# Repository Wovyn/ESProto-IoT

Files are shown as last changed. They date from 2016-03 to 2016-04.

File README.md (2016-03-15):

# ESProto-IoT

The ESProto IoT is an ESP8266 prototyping PCB made for the AI Thinker ESP-12F modules, and designed to support IoT ("Internet of Things") sensors and peripherals from SeeedStudio/Grove, DFRobot, and ControlEverything.

## How does it work?

The ESP8266 is more powerful than the Arduino Pro Mini--so why not use it as the "main" microcontroller, and drive the Arduino Pro Mini as a peripheral? We do that by communicating with the Arduino Pro Mini over I2C ("I-squared-C"). The advantage to this arrangement is a board that can speak to all of the 5V sensors and actuators that already work with your Arduino, with the added speed and WiFi capability of the ESP8266.

## Design Images

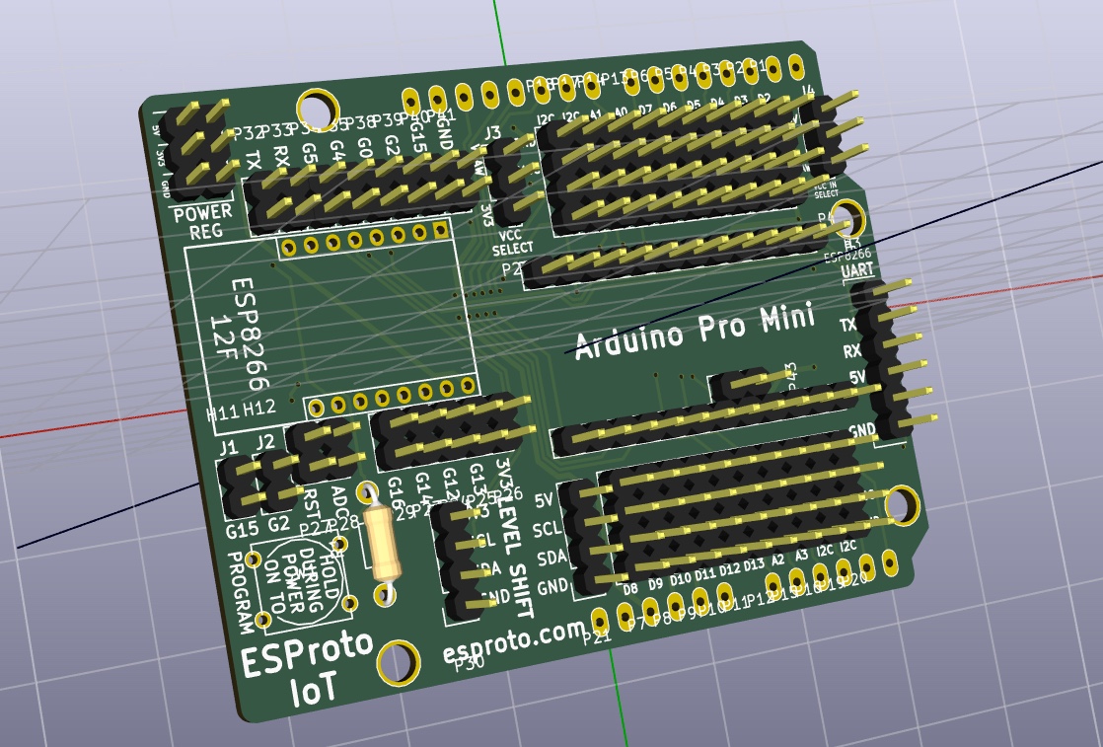
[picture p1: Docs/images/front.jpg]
Front


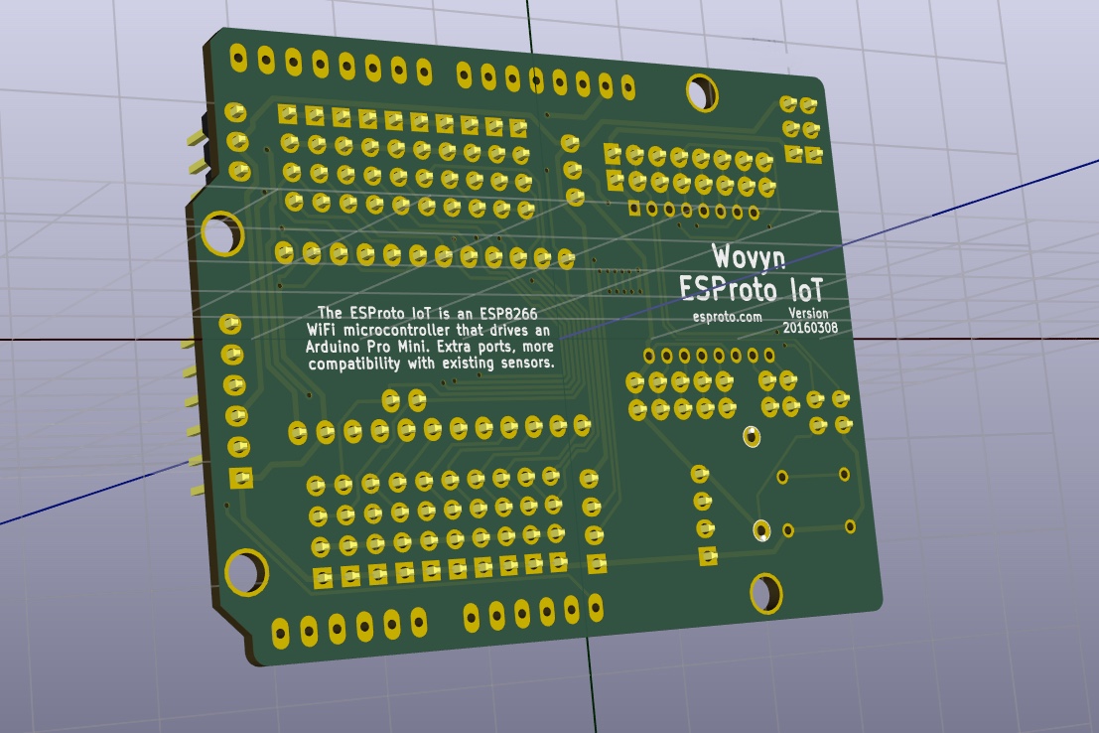
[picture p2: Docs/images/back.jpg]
Back


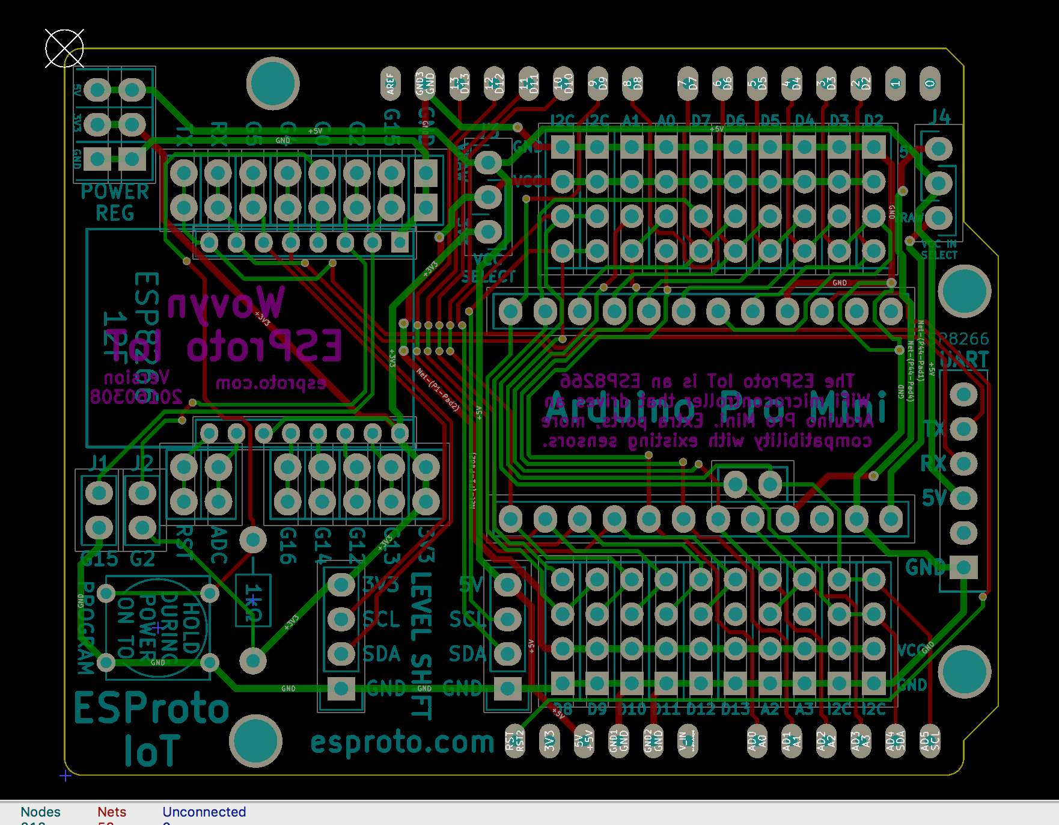
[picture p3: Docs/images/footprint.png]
Footprint


## PDFs

[View PDFs](Docs/PDF)

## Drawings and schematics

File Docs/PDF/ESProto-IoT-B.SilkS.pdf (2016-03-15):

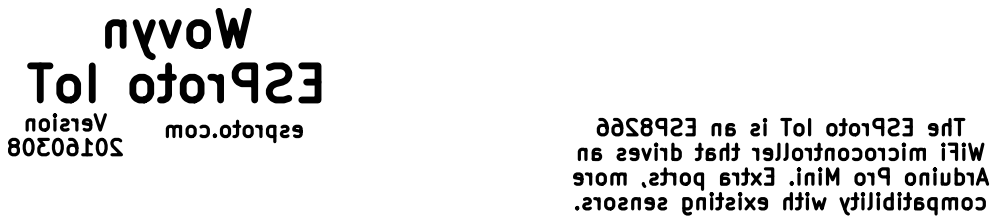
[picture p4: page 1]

20160308 The ESProto IoT is an ESP8266 WiFi microcontroller that drives an Arduino Pro Mini. Extra ports, more

compatibility with existing sensors.

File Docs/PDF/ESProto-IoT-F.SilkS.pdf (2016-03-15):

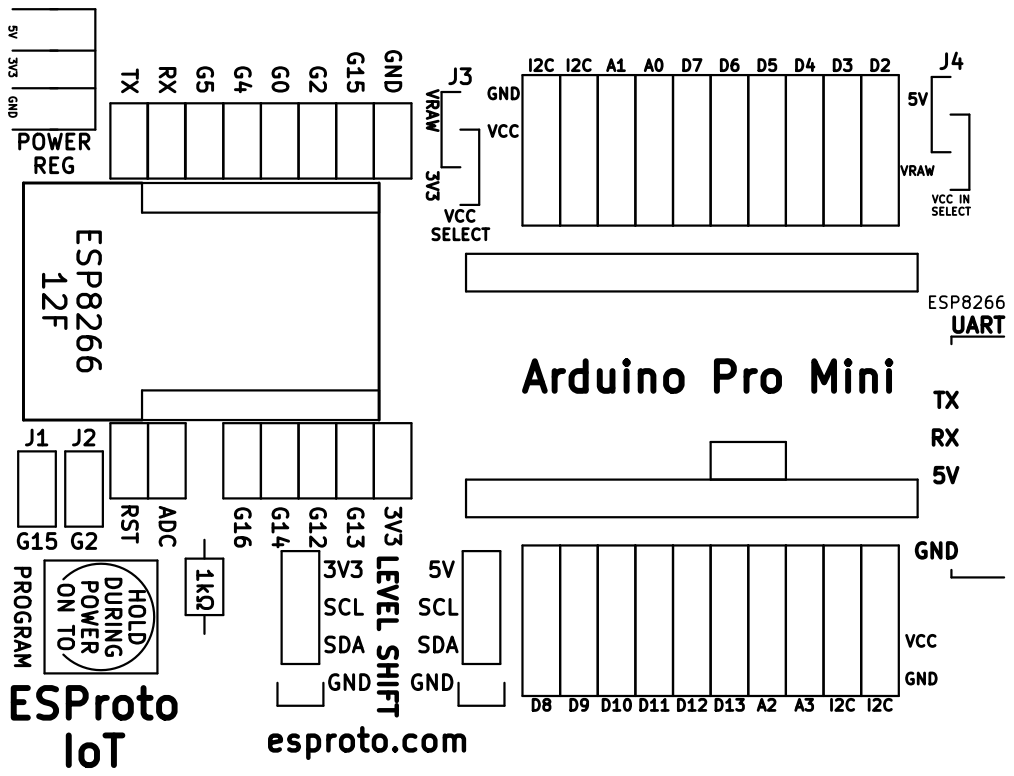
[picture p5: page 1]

SCL SDA G14 G12 G13 3V3 GND 3V3 5V POWER

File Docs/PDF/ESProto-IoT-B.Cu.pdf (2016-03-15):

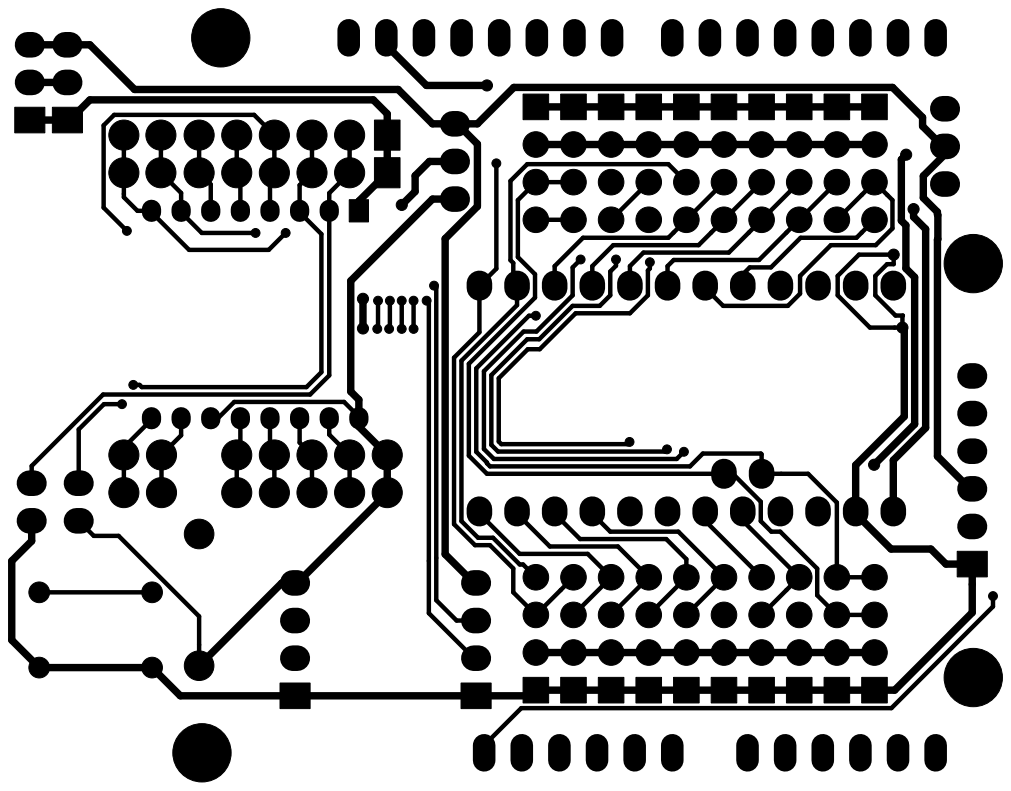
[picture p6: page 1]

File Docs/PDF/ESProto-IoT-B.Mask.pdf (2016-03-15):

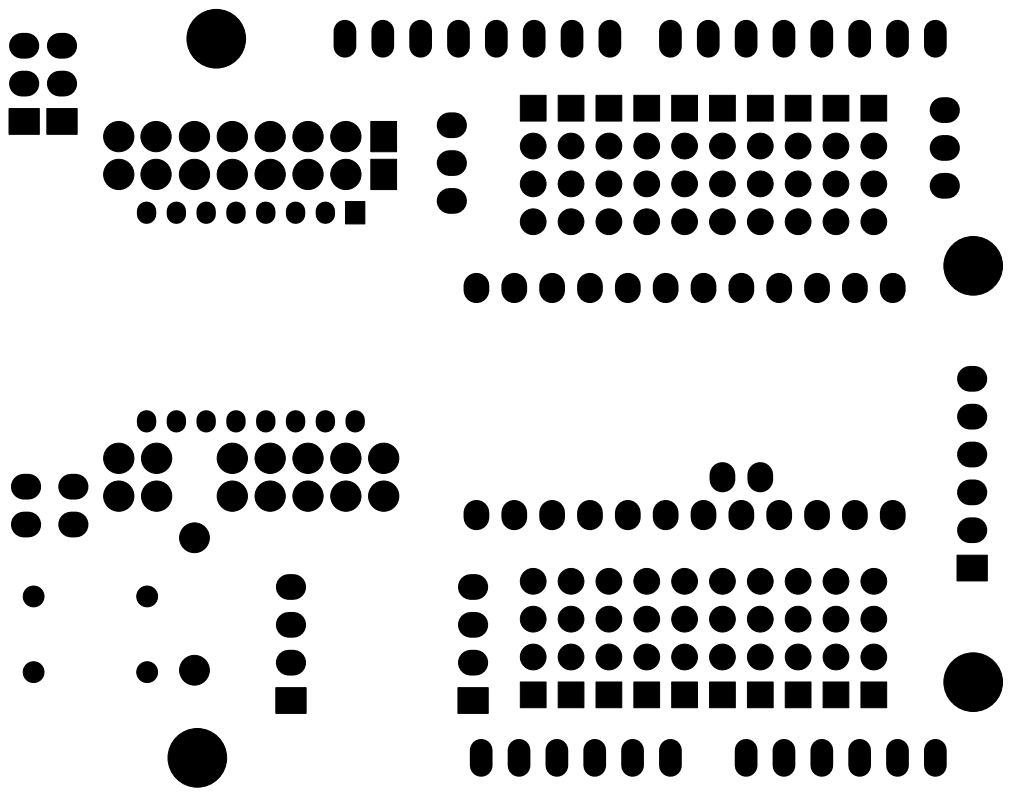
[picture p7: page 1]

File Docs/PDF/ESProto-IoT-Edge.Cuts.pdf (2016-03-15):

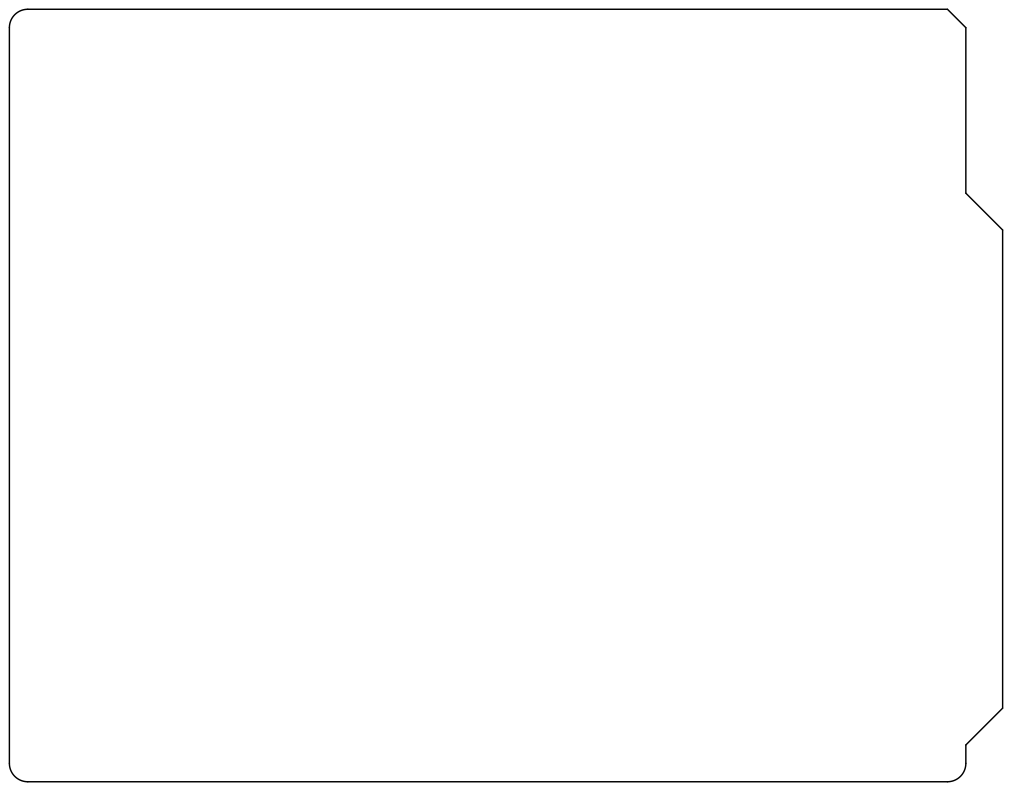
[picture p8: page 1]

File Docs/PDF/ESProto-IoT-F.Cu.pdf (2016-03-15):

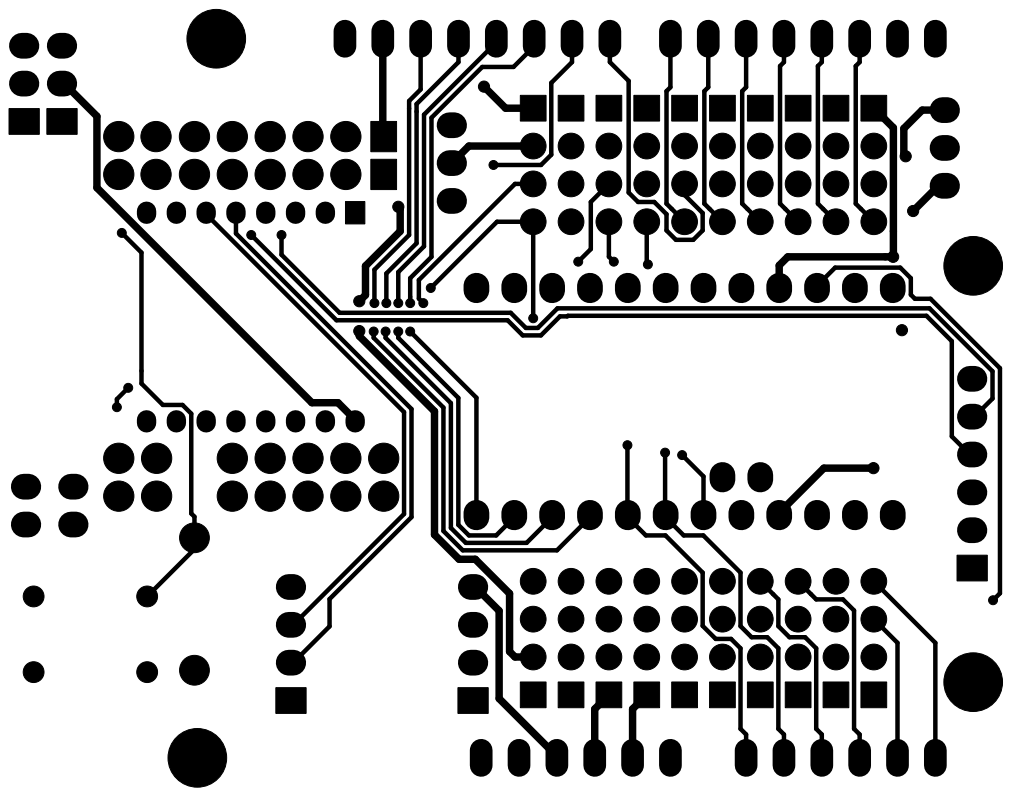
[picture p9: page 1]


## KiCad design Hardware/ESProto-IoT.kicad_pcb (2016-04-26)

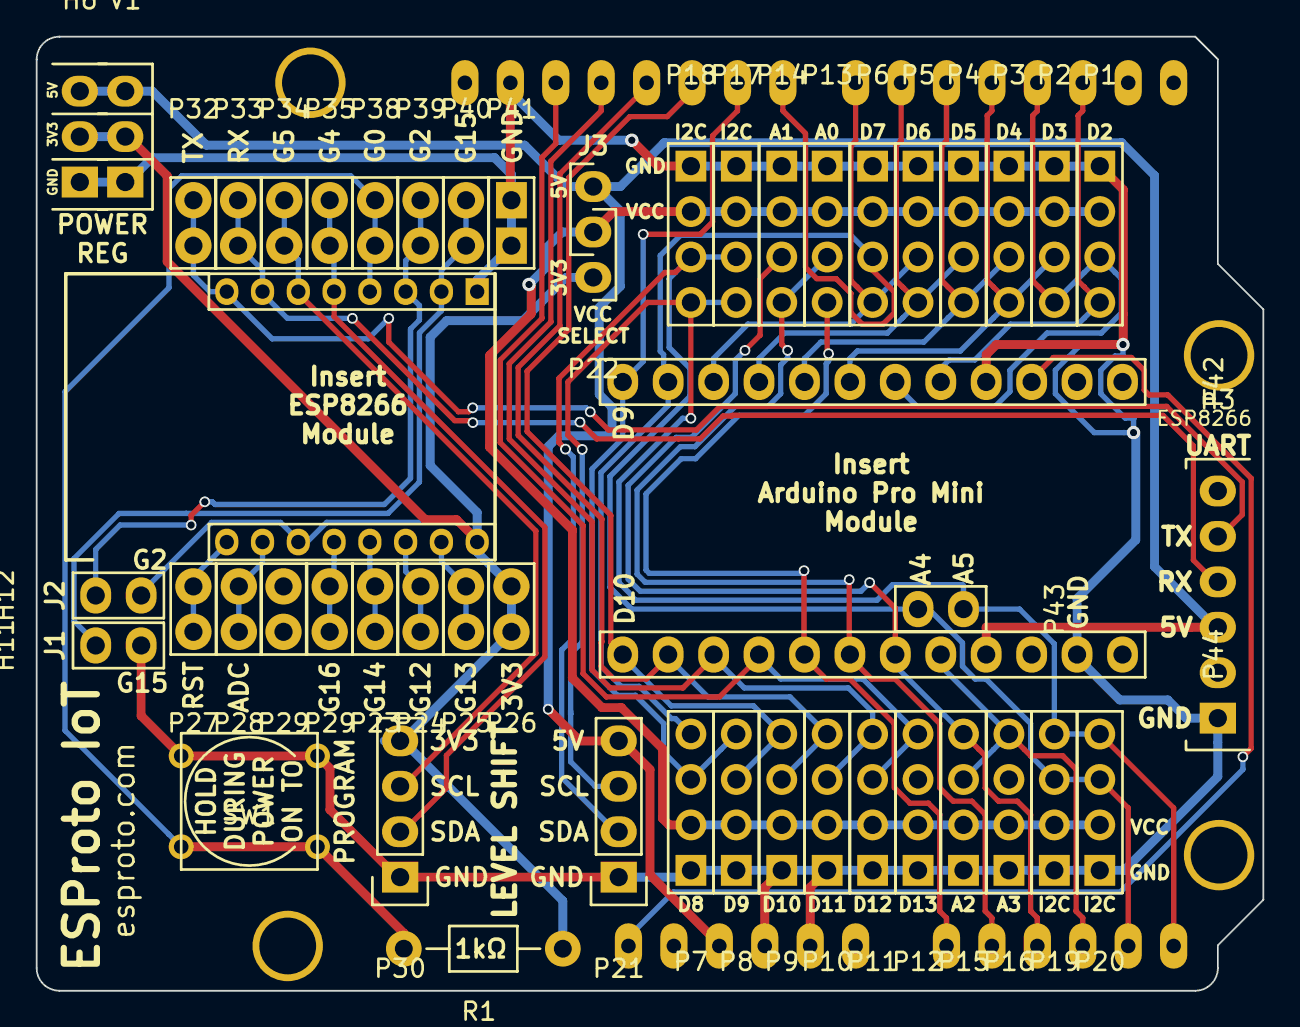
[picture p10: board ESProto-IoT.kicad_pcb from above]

Board: 2 copper layers, 68.6 x 53.3 mm, 52 parts (0 on the bottom side), 36 nets.

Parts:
H3: UART; Pin_Header_Straight_1x06
H5: L0; Pin_Header_Straight_1x08_Pitch2.00mm
H6: VRegOut; Pin_Header_Straight_1x03
H7: R0; Pin_Header_Straight_1x08_Pitch2.00mm
H11: GPIO15_GND; Pin_Header_Straight_1x02
H12: GPIO2_VCC; Pin_Header_Straight_1x02
IC1: ARDUINO_PRO_MINI_5V; ARDUINO_SHIELD
P1: DIGITAL_02; Pin_Header_Straight_1x04_C
P2: DIGITAL_03; Pin_Header_Straight_1x04_C
P3: DIGITAL_04; Pin_Header_Straight_1x04_C
P4: DIGITAL_05; Pin_Header_Straight_1x04_C
P5: DIGITAL_06; Pin_Header_Straight_1x04_C
P6: DIGITAL_07; Pin_Header_Straight_1x04_C
P7: DIGITAL_08; Pin_Header_Straight_1x04_C
P8: DIGITAL_09; Pin_Header_Straight_1x04_C
P9: DIGITAL_10; Pin_Header_Straight_1x04_C
P10: DIGITAL_11; Pin_Header_Straight_1x04_C
P11: DIGITAL_12; Pin_Header_Straight_1x04_C
P12: DIGITAL_13X; Pin_Header_Straight_1x04_C
P13: ANALOG_00; Pin_Header_Straight_1x04_C
P14: ANALOG_01; Pin_Header_Straight_1x04_C
P15: ANALOG_02; Pin_Header_Straight_1x04_C
P16: ANALOG_03X; Pin_Header_Straight_1x04_C
P17: I2C_01; Pin_Header_Straight_1x04_C
P18: I2C_02; Pin_Header_Straight_1x04_C
P19: I2C_03; Pin_Header_Straight_1x04_C
P20: I2C_04; Pin_Header_Straight_1x04_C
P21: LEVEL_A; Pin_Header_Straight_1x04
P22: POWER_A; Pin_Header_Straight_1x03
P23: ESP_G14; Pin_Header_Straight_1x02
P24: ESP_G12; Pin_Header_Straight_1x02
P25: ESP_G13; Pin_Header_Straight_1x02
P26: ESP_3V3; Pin_Header_Straight_1x02
P27: ESP_RST; Pin_Header_Straight_1x02
P28: ESP_ADC; Pin_Header_Straight_1x02
P29, P29#2: ESP_G16; Pin_Header_Straight_1x02
P30: LEVEL_B; Pin_Header_Straight_1x04
P32: ESP_TX; Pin_Header_Straight_1x02
P33: ESP_RX; Pin_Header_Straight_1x02
P34: ESP_G5; Pin_Header_Straight_1x02
P35: ESP_G4; Pin_Header_Straight_1x02
P38: ESP_G0; Pin_Header_Straight_1x02
P39: ESP_G2; Pin_Header_Straight_1x02
P40: ESP_G15; Pin_Header_Straight_1x02
P41: ESP_GND; Pin_Header_Straight_1x02
P42: ARDUINO_L; Pin_Header_Straight_1x12
P43: I2C_A4_A5; Pin_Header_Straight_1x02
P44: ARDUINO_R; Pin_Header_Straight_1x12
R1: 1kΩ; Resistor_Horizontal_RM10mm
SW1: PROGRAM; SW_PUSH_SMALL
V1: Voltage_Regulator; Pin_Header_Straight_1x03

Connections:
+3V3: H5.3, H5.8, H6.2, H12.2, P22.1, P26.1, P26.2, P30.4, R1.1, V1.2
+5V: H3.4, H6.1, IC1.5V, P21.4, P22.3, P44.4, V1.1
A0: IC1.AD0, P13.4, P44.8
A1: IC1.AD1, P13.3, P14.4, P44.7
A2: IC1.AD2, P14.3, P15.4, P44.6
A3: IC1.AD3, P15.3, P16.4, P44.5
ADC: H5.2, P28.1, P28.2
D2: IC1.2, P1.4, P42.5
D3: IC1.3, P1.3, P2.4, P42.6
D4: IC1.4, P2.3, P3.4, P42.7
D5: IC1.5, P3.3, P4.4, P42.8
D6: IC1.6, P4.3, P5.4, P42.9
D7: IC1.7, P5.3, P6.4, P42.10
D8: IC1.8, P6.3, P7.4, P42.11
D9: IC1.9, P7.3, P8.4, P42.12
D10: IC1.10, P8.3, P9.4, P44.12
D11: IC1.11, P9.3, P10.4, P44.11
D12: IC1.12, P10.3, P11.4, P44.10
D13: IC1.13, P11.3, P12.4, P44.9
GND: H3.6, H6.3, H7.8, H11.2, IC1.GND1, IC1.GND2, IC1.GND3, P1.1, P2.1, P3.1, P4.1, P5.1, P6.1, P7.1, P8.1, P9.1, P10.1, P11.1, P12.1, P13.1, P14.1, P15.1, P16.1, P17.1, P18.1, P19.1, P20.1, P21.1, P30.1, P41.1, P41.2, P42.4, P44.2, SW1.2, V1.3
GPIO0: H7.5, P38.1, P38.2, R1.2, SW1.1
GPIO2: H7.6, H12.1, P39.1, P39.2
GPIO12: H5.6, P24.1, P24.2
GPIO13: H5.7, P25.1, P25.2
GPIO14: H5.5, P23.1, P23.2
GPIO15: H7.7, H11.1, P40.1, P40.2
GPIO16: H5.4, P29#2.1, P29#2.2
unnamed: P1.2, P2.2, P3.2, P4.2, P5.2, P6.2, P7.2, P8.2, P9.2, P10.2, P11.2, P12.2, P13.2, P14.2, P15.2, P16.2, P17.2, P18.2, P19.2, P20.2, P22.2
REST: H5.1, P27.1, P27.2
RST2: IC1.RST, P42.3
RXD1: H3.3, H7.2, P33.1, P33.2
SCL: IC1.AD5, P17.4, P18.4, P19.4, P20.4, P21.3, P43.1
SCL_ESP: H7.3, P30.3, P34.1, P34.2
SDA: IC1.AD4, P17.3, P18.3, P19.3, P20.3, P21.2, P43.2
SDA_ESP: H7.4, P30.2, P35.1, P35.2
TXD1: H3.2, H7.1, P32.1, P32.2

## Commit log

2016-02-09 Add KiCad schema, pcb files
    [ESProto-IoT.kicad_pcb, ESProto-IoT.sch]
2016-03-13 Update to v20160308
    [ESProto-IoT.kicad_pcb, ESProto-IoT.sch]
2016-03-15 Updated IoT
    [ESProto-IoT.kicad_pcb]
2016-04-21 Update to add more space, better labels
    [ESProto-IoT.kicad_pcb, ESProto-IoT.sch]
2016-04-26 Latest PCB
    [ESProto-IoT.kicad_pcb]
